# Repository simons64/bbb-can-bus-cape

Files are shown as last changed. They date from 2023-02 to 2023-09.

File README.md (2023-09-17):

# bbb-can-bus-cape
beaglebone black cape:
- 4x CANbus (up to 1Mbit, 2x direct CAN, 2x MCP2515)
- 1x RS485 up to 10 Mbit

## __design untested yet !__

Credits for the design to [@voloviq/bbb-can-bus-cape](https://github.com/voloviq/bbb-can-bus-cape)  
Design was adjusted for:
- currently available components from jlcpcb
- compatible interface for home ESS (Victron Multiplus 2 ; Victron MPPT RS 450 ; Pylontech US5000C)

## board 3D view

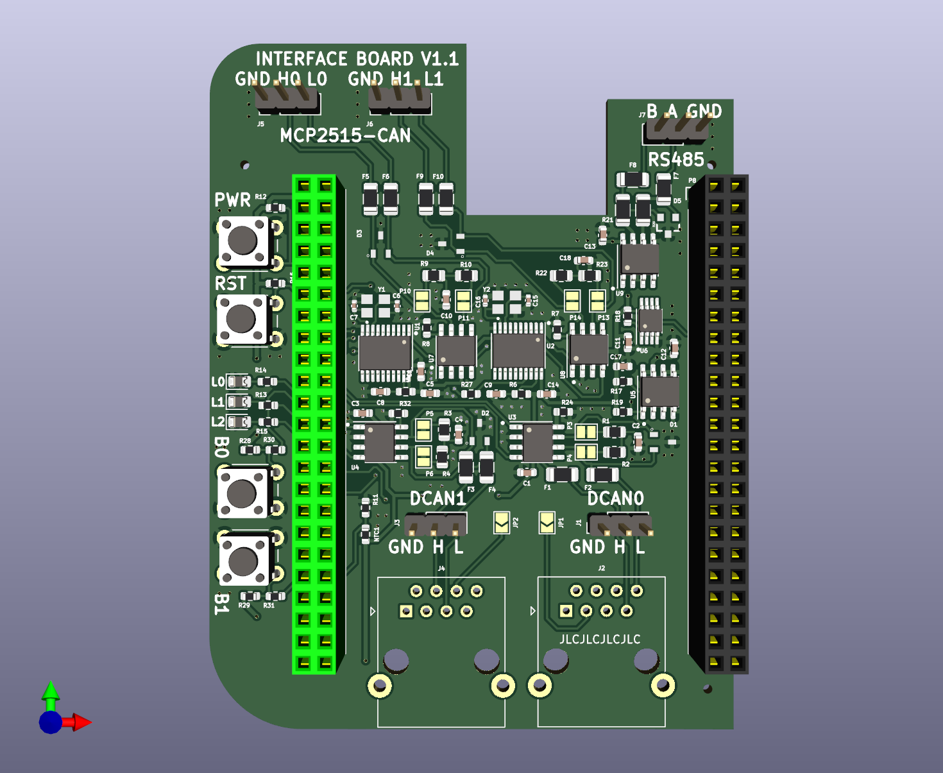
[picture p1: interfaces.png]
PCB_3D


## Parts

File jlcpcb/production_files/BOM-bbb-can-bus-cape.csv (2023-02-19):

Comment | Designator | Footprint | LCSC
SN65HVD230 | U3,U4,U7,U8 | SOIC-8_3.9x4.9mm_P1.27mm | C12084
X322516MLB4SI | Y1,Y2 | OSC_X322516MLB4SI | C13738
100nF/50V | C1,C10,C11,C12,C13,C14,C17,C18,C19,C2,C3,C4,C5,C8,C9 | C_0603_1608Metric | C14663
60R | R1,R10,R2,R22,R23,R3,R4,R9 | R_0805_2012Metric | C17757
10R | R20,R21 | R_1206_3216Metric | C17903
100R | R13,R14,R15,R27,R30,R31 | R_0603_1608Metric | C22775
LED | D6 | D_0805_2012Metric | C2296
LED | D7 | D_0805_2012Metric | C2297
4k7 | R11,R12,R16,R17,R18,R19,R28,R29 | R_0603_1608Metric | C23162
10k | R24,R32,R5,R6,R7,R8 | R_0603_1608Metric | C25804
PSM712 | D5 | SOT23-3 | C32677
10pF/50V | C15,C16,C6,C7 | C_0402_1005Metric | C32949
Polyfuse_Small | F1,F10,F2,F3,F4,F5,F6,F7,F8,F9 | Fuse_1206_3216Metric | C438898
PESD2CAN,215 | D1,D2,D3,D4 | SOT95P230X110-3N | C75176
LED | D8 | D_0805_2012Metric | C84256
SP3485EN | U9 | SOIC-8_3.9x4.9mm_P1.27mm | C8963

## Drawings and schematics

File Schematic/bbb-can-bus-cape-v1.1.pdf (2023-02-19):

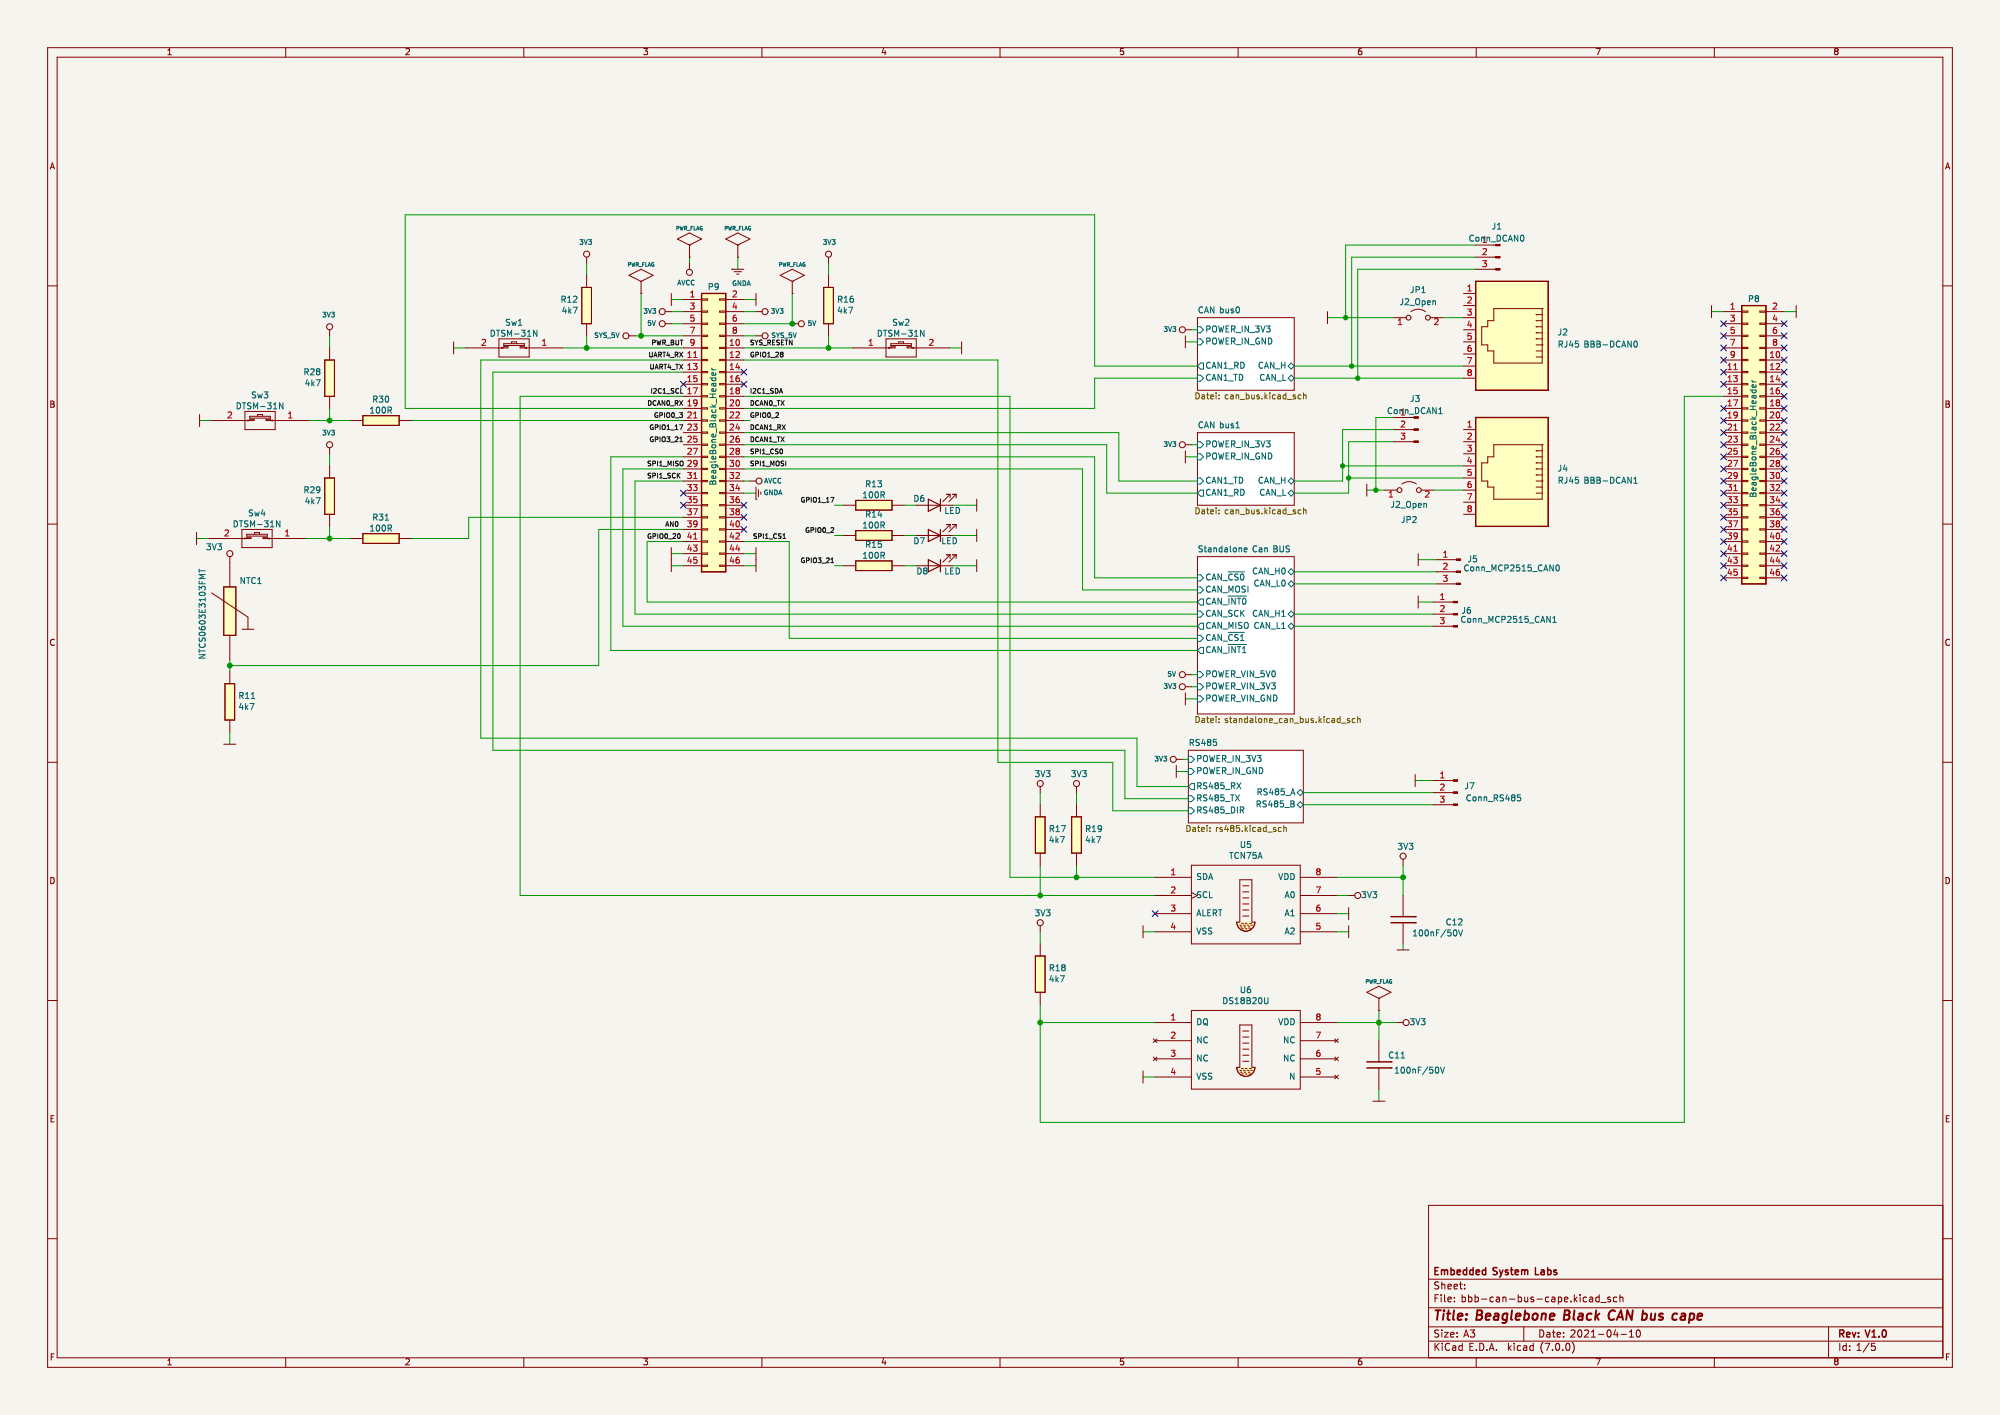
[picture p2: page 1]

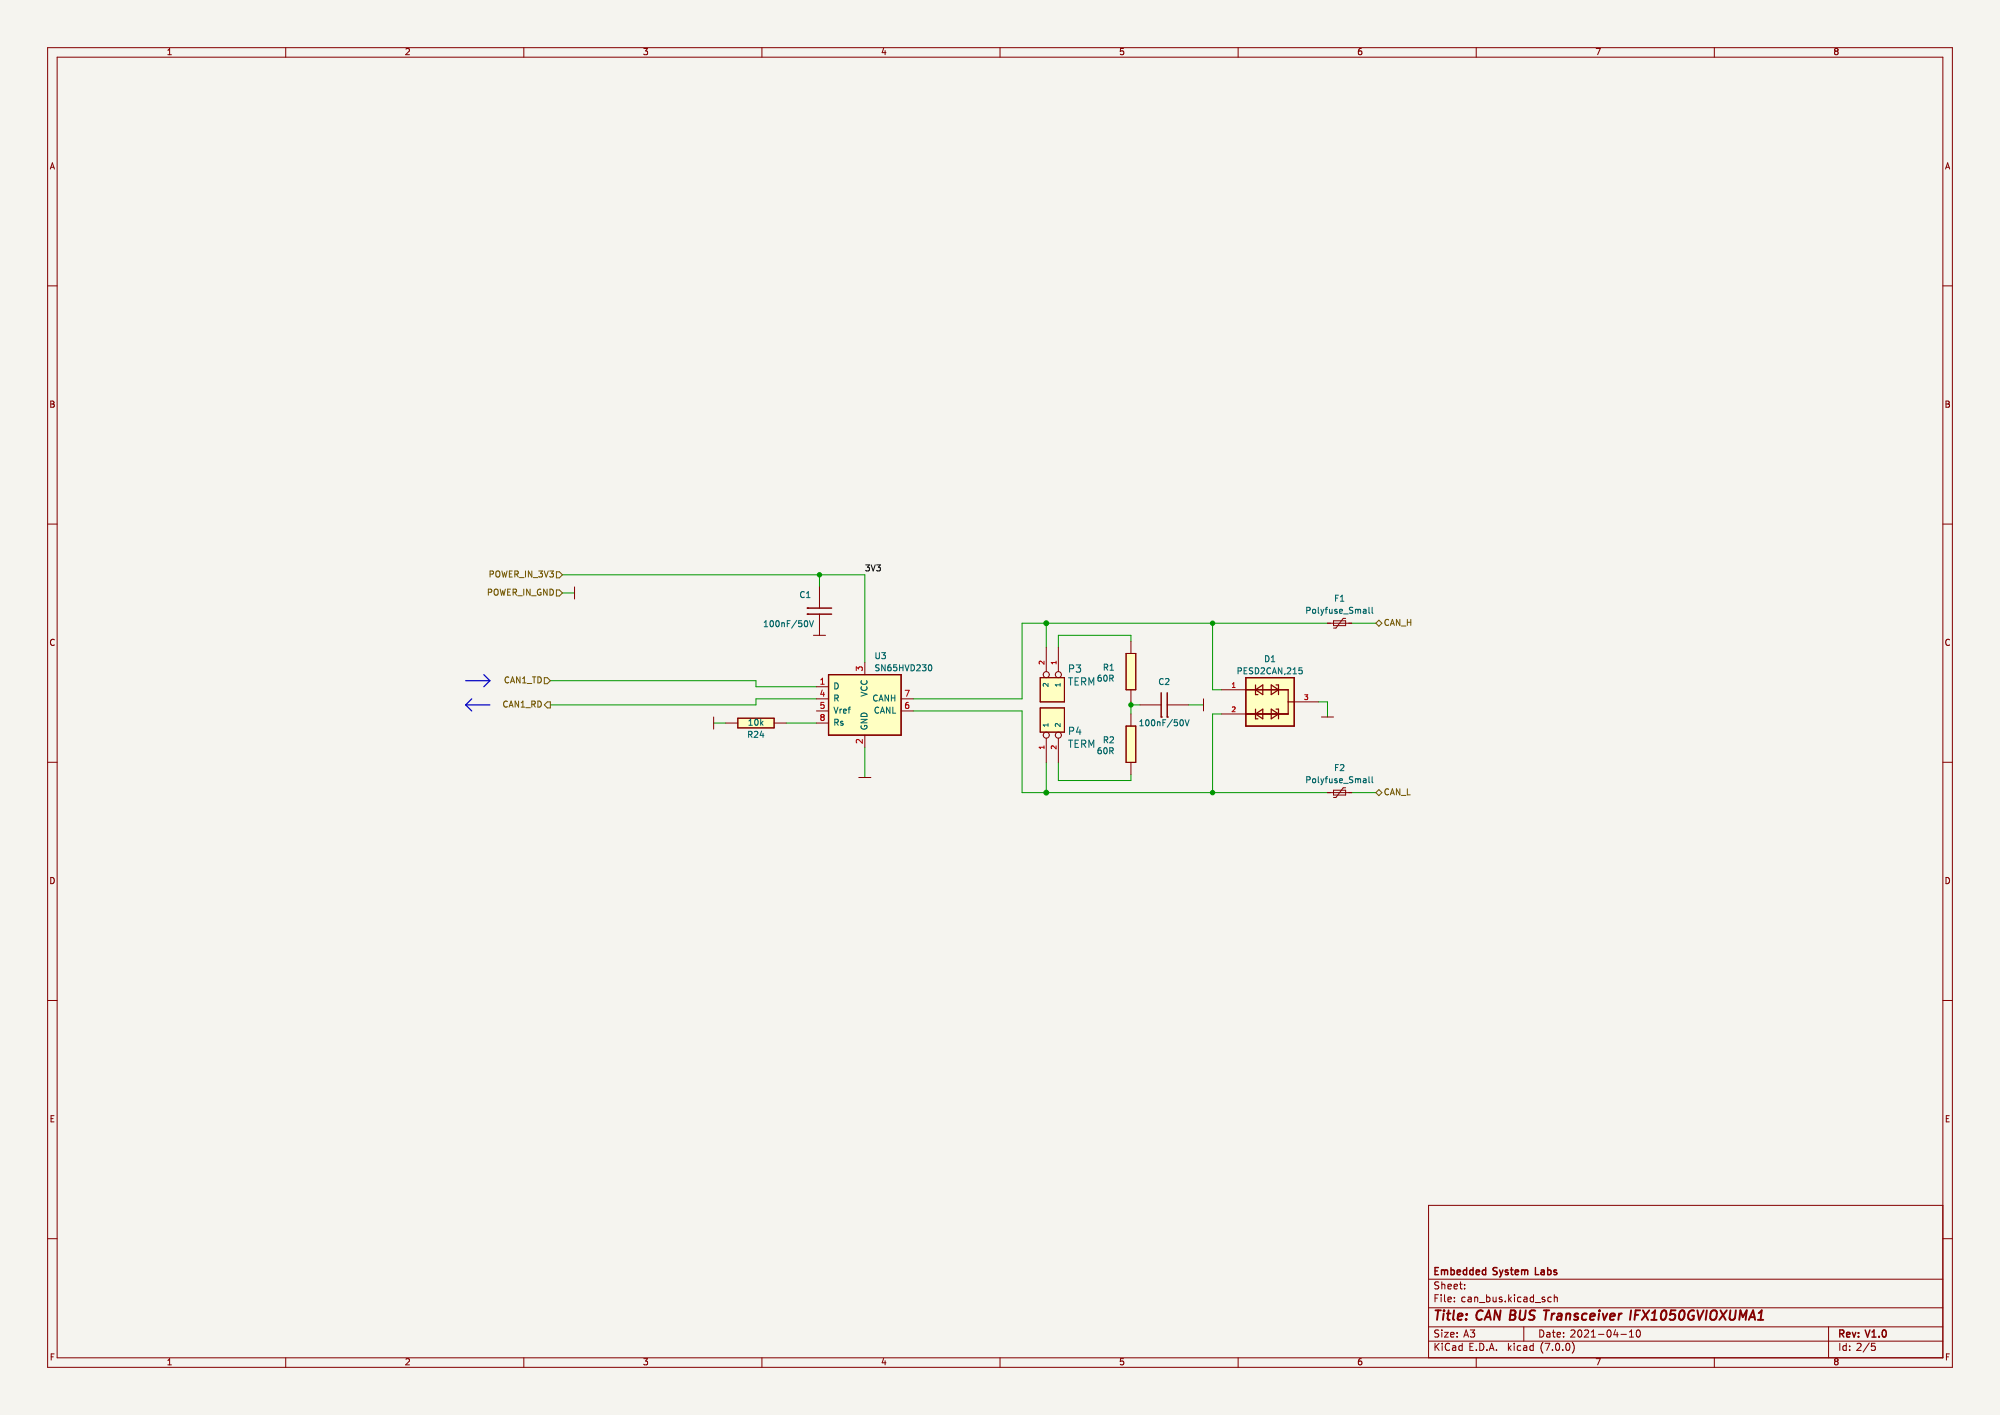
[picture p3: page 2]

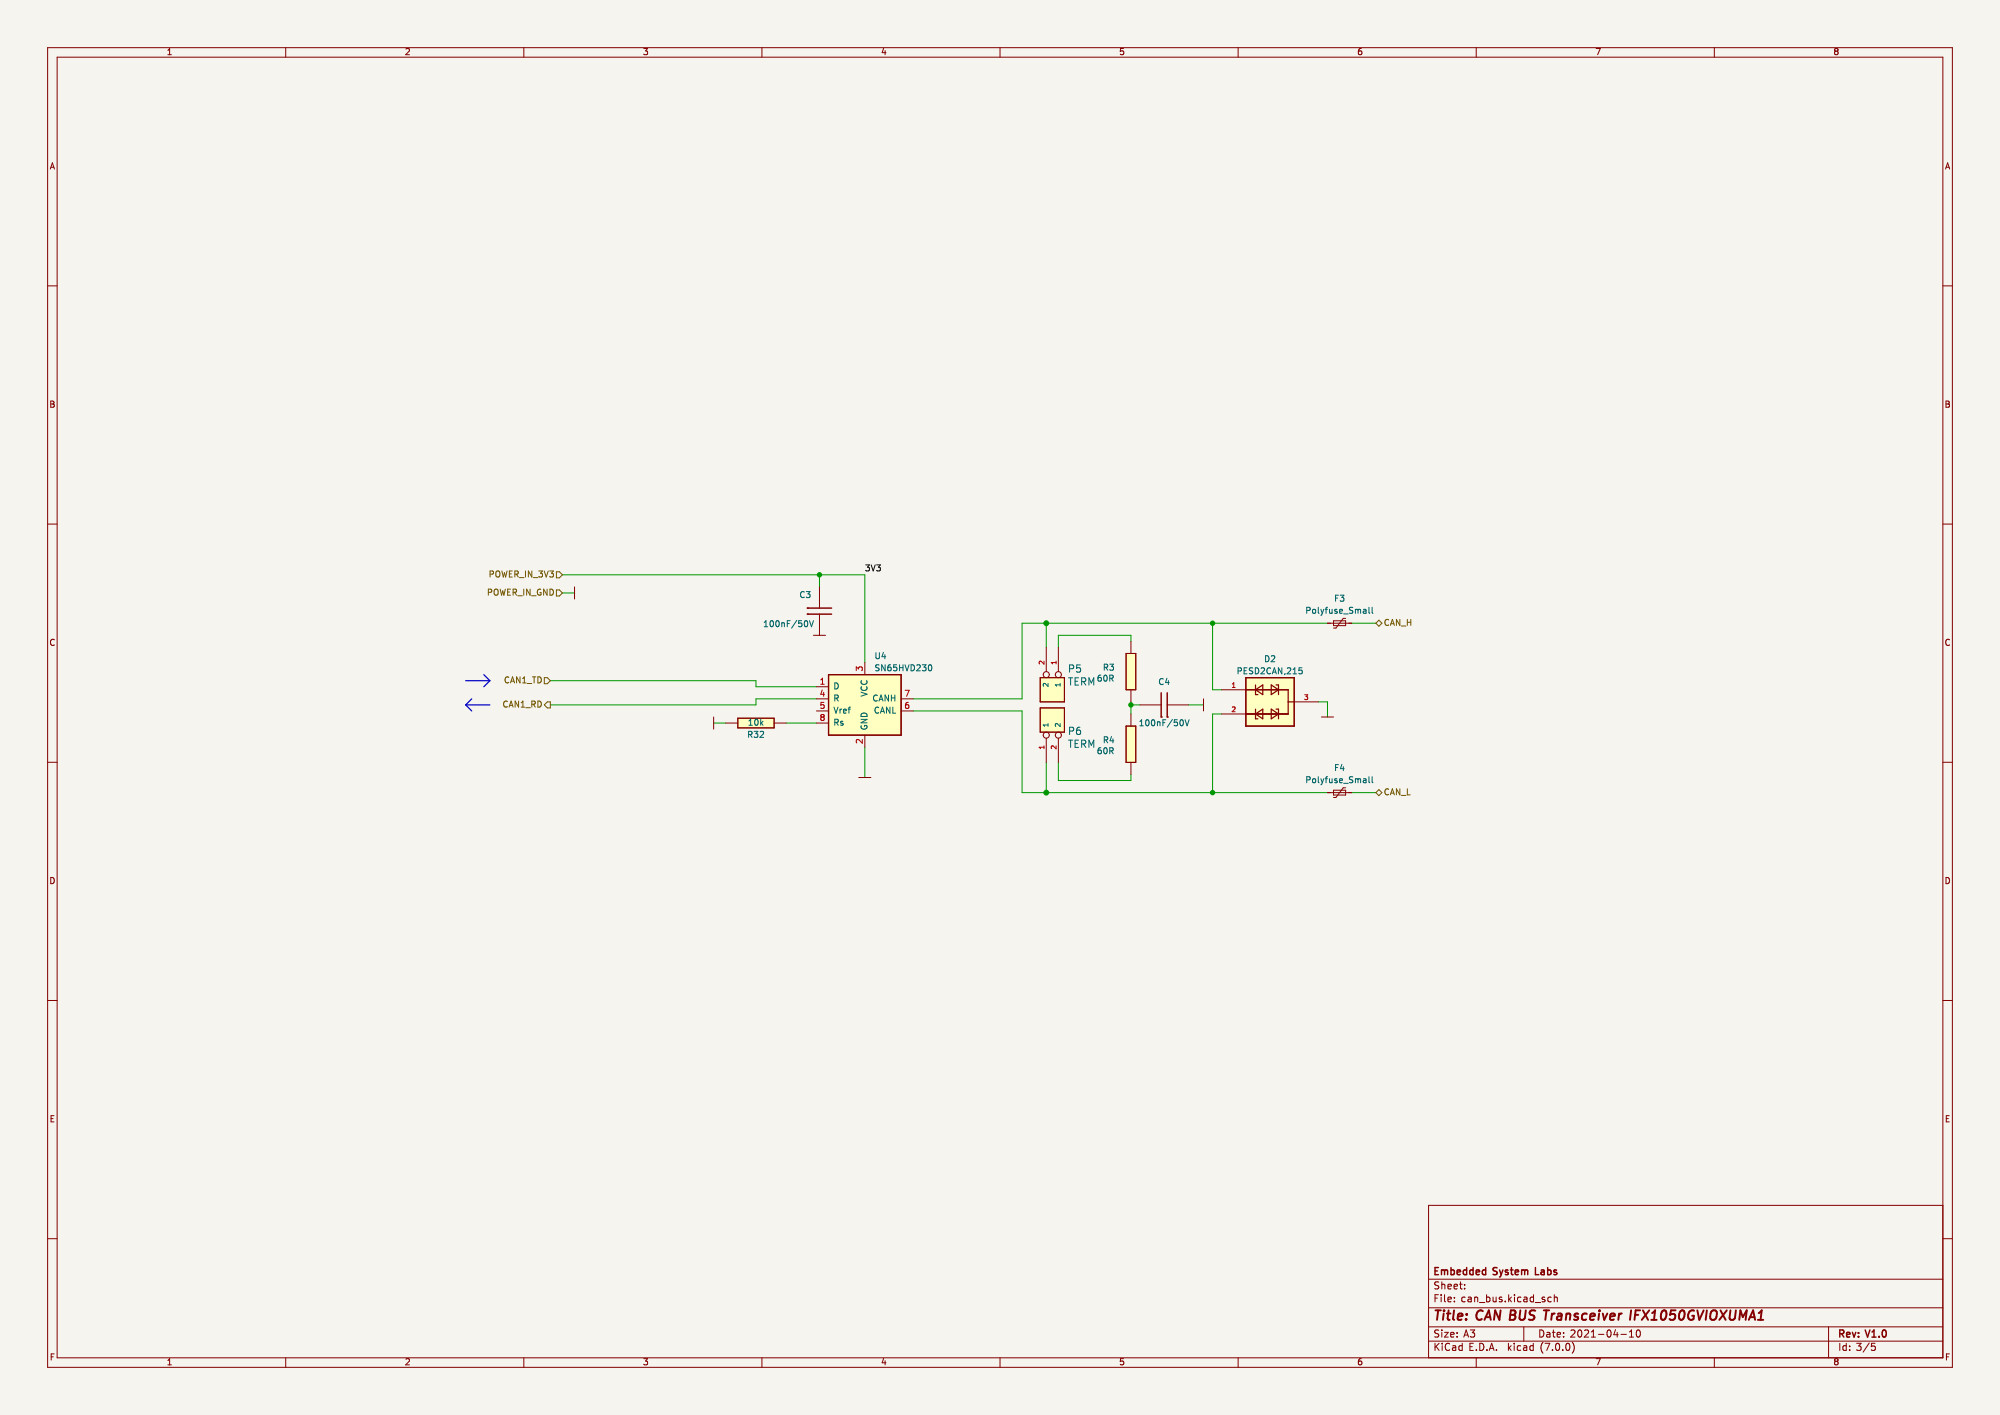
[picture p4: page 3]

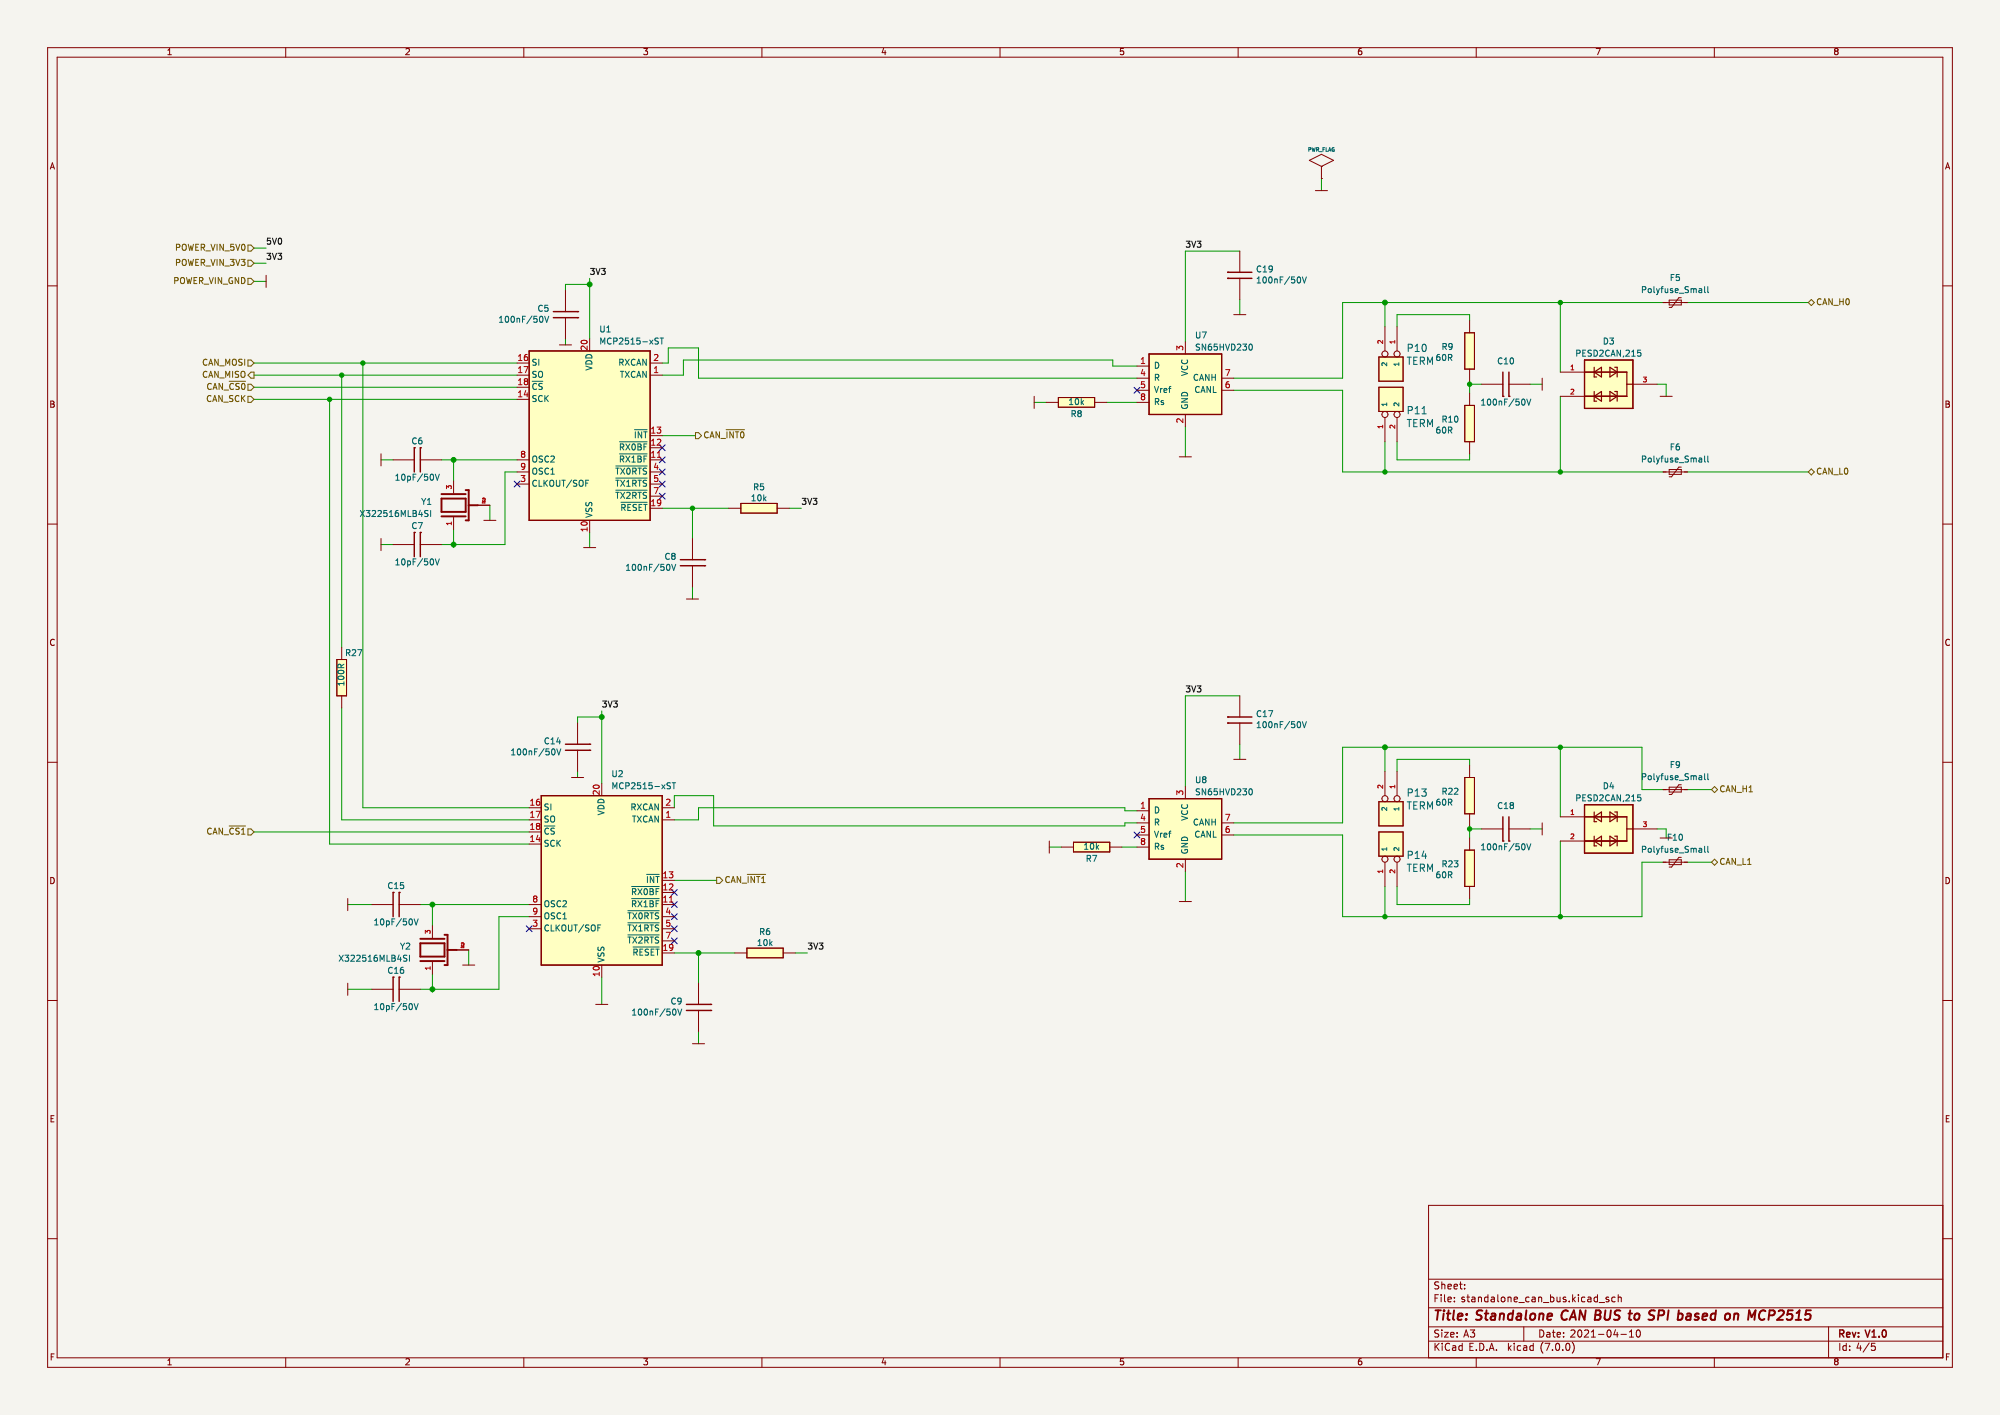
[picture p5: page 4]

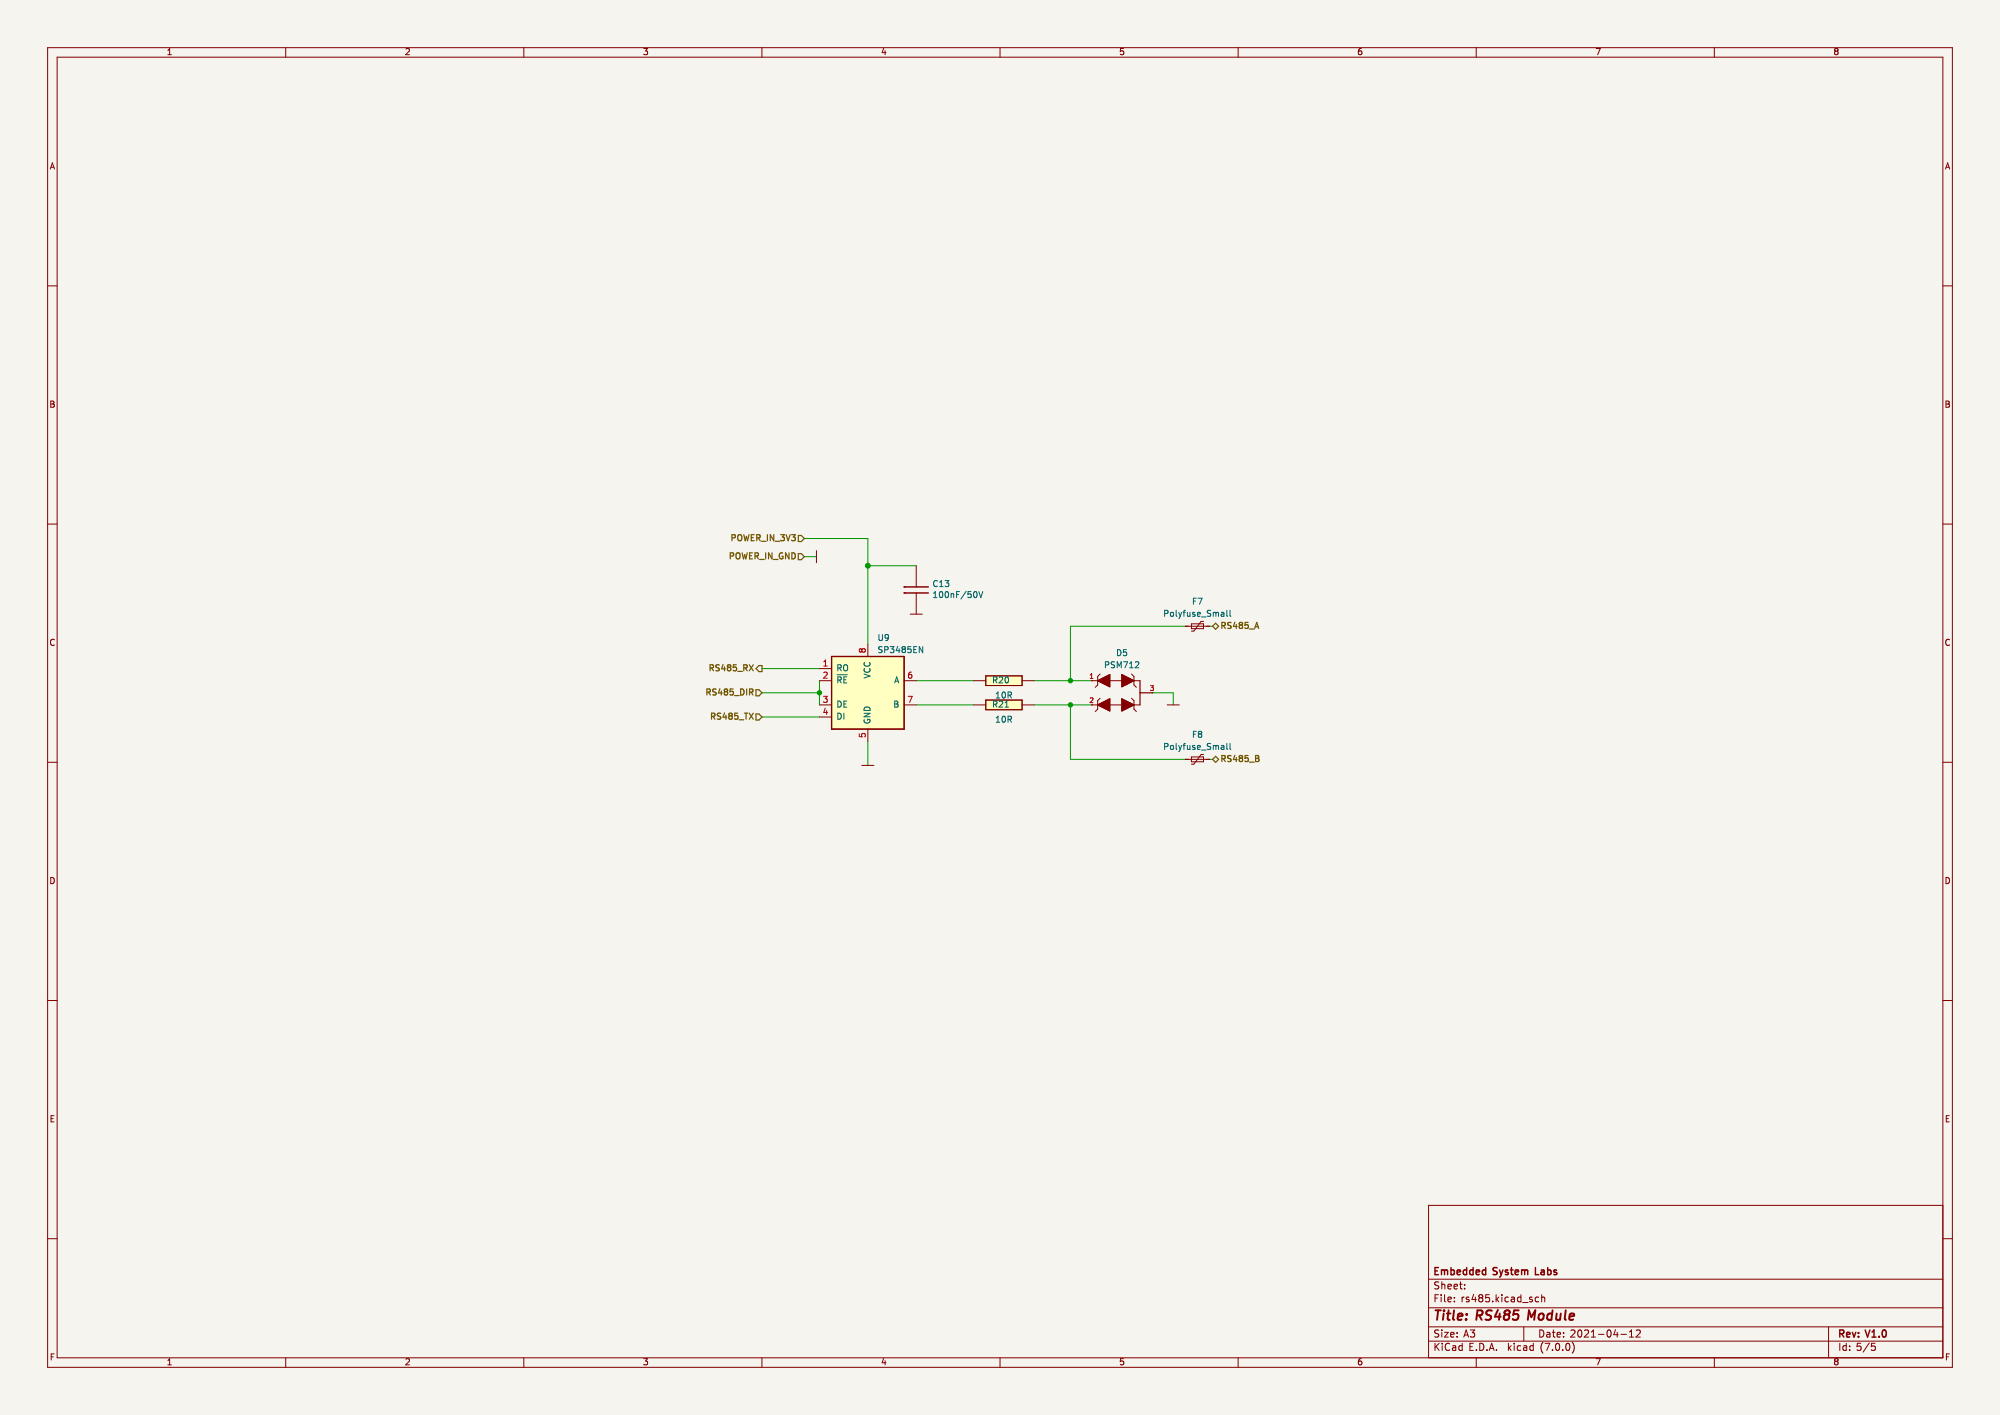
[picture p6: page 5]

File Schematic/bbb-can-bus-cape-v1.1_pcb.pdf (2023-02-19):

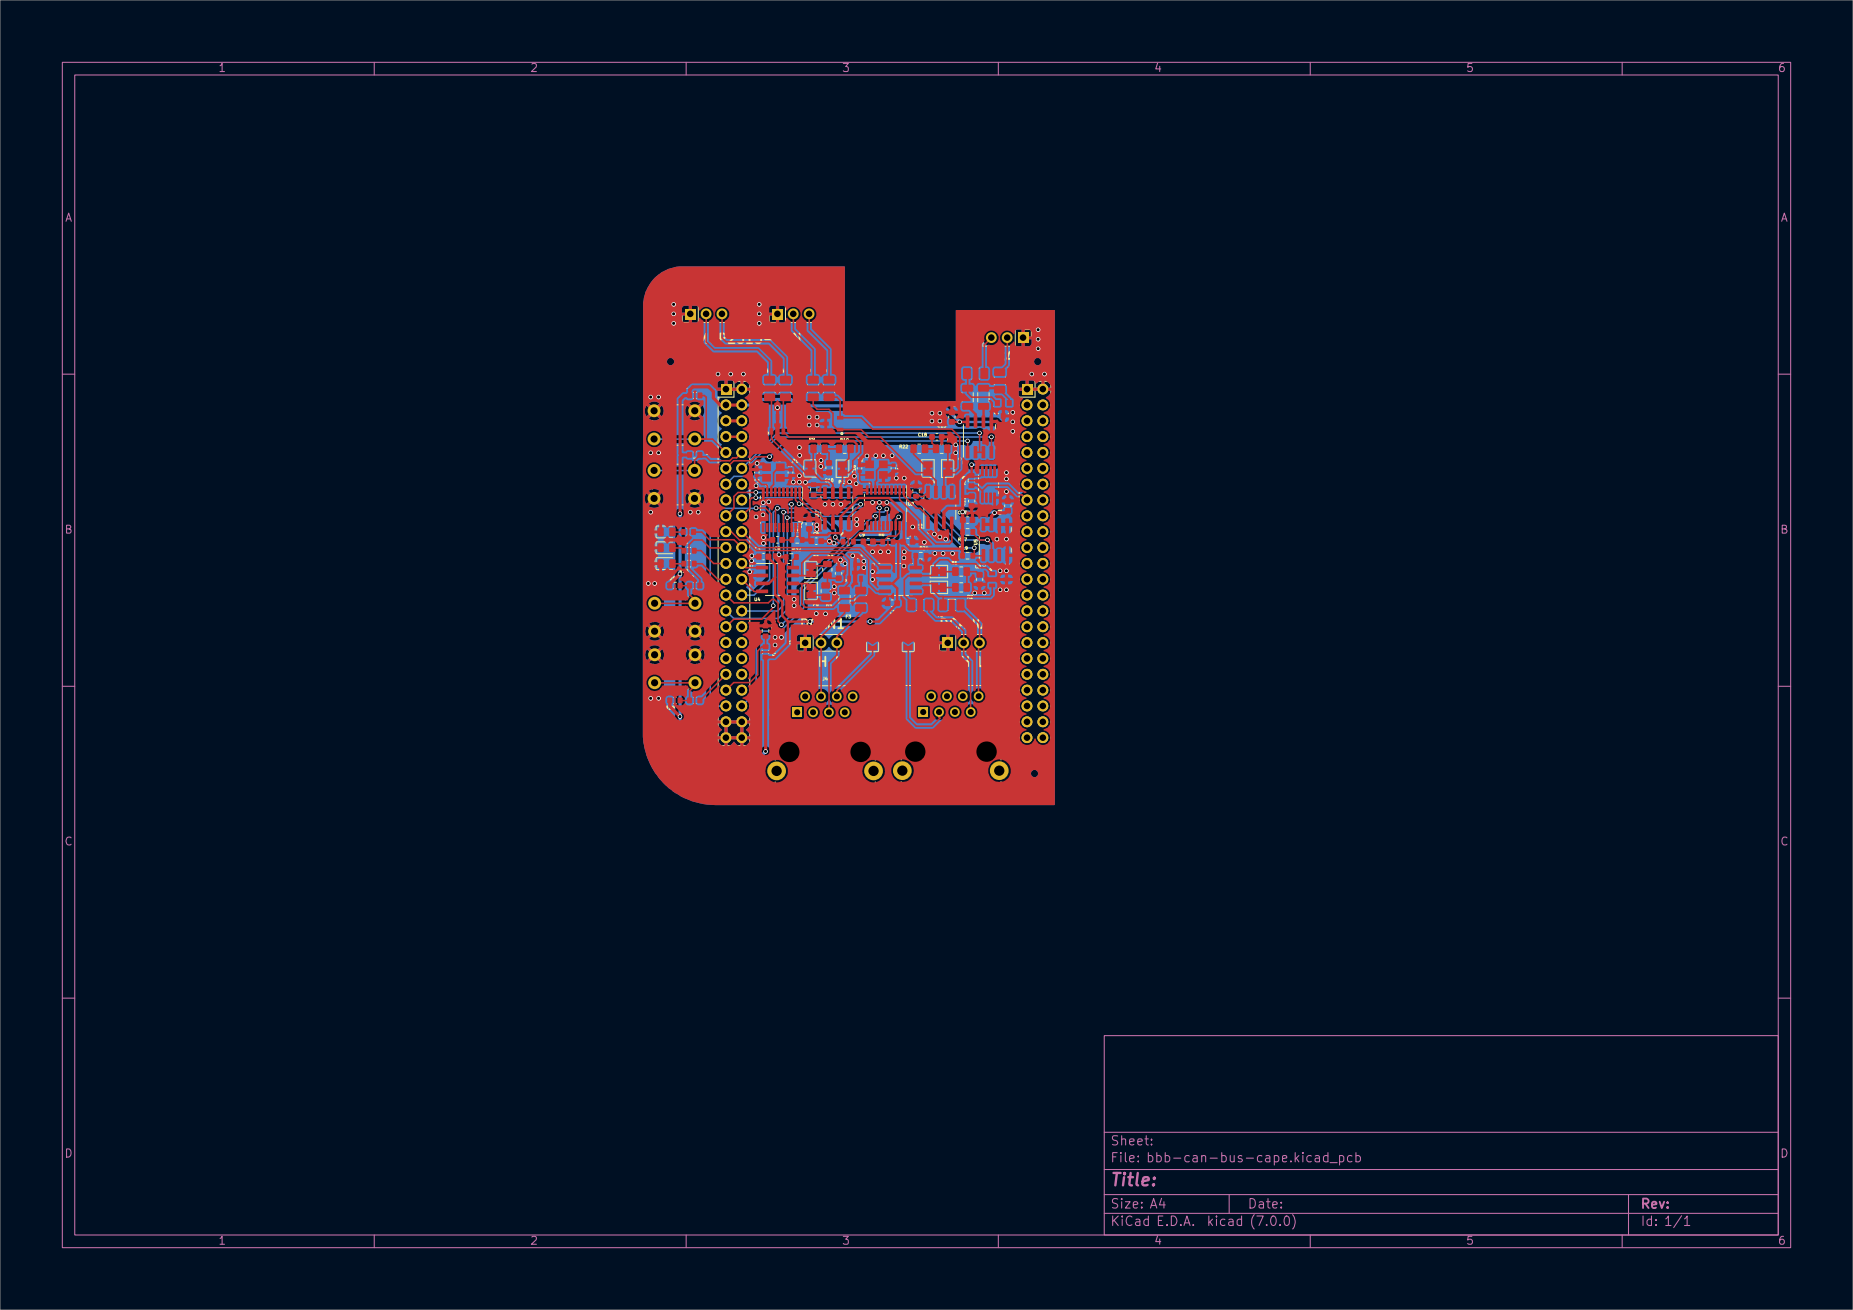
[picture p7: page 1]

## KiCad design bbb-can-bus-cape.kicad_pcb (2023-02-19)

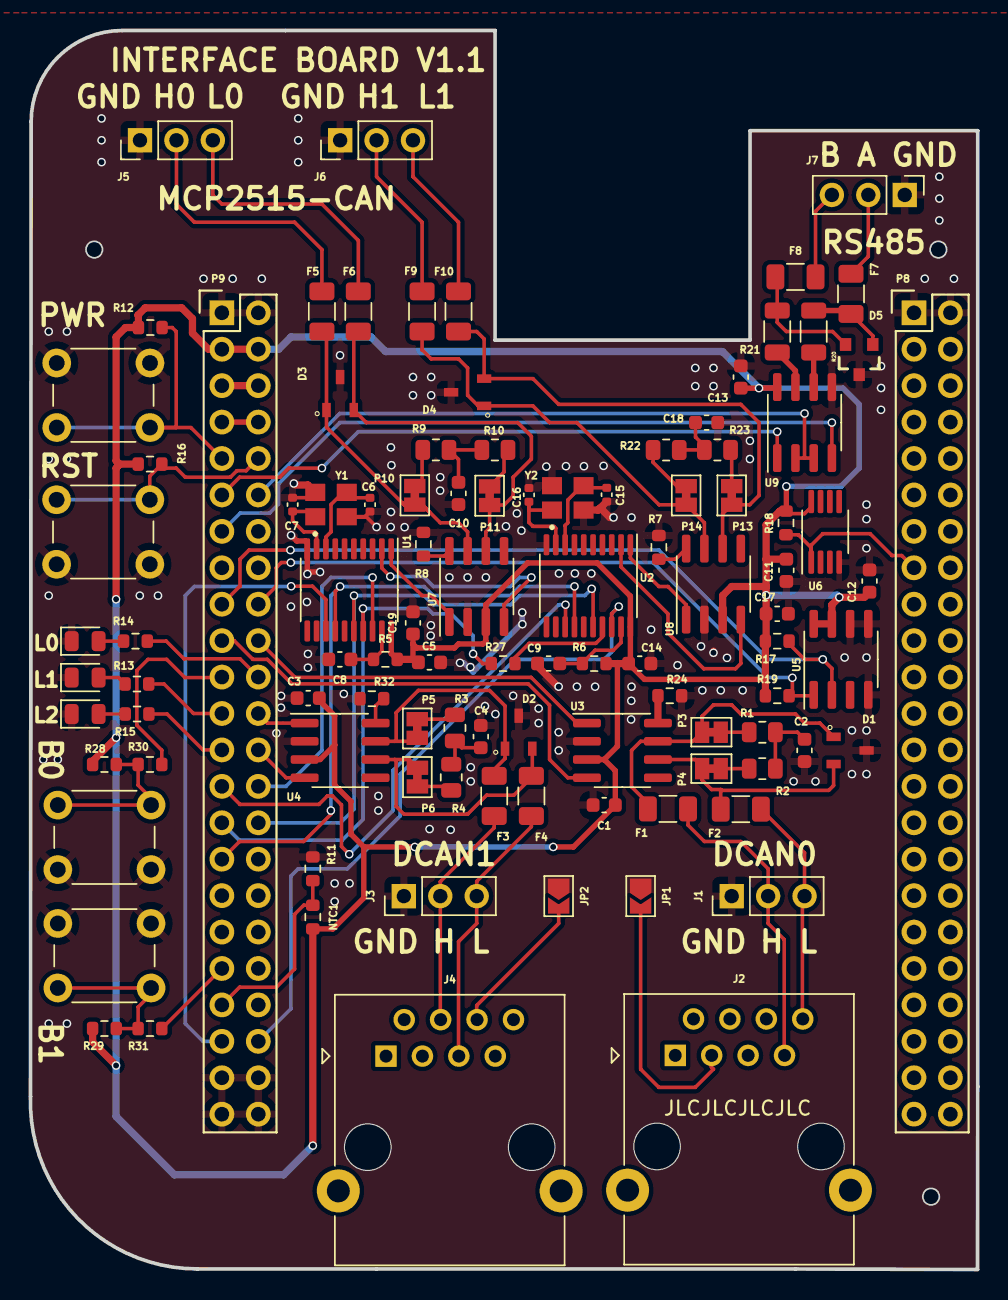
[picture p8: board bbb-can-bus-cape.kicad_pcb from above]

Board: 2 copper layers, 66.0 x 86.4 mm, 102 parts (0 on the bottom side), 85 nets.

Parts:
C1, C2, C3, C4, C5, C8, C9, C10, C11, C12, C13, C14, C17, C18, C19: 100nF/50V; C_0603_1608Metric
C6, C7, C15, C16: 10pF/50V; C_0402_1005Metric
D1, D2, D3, D4: PESD2CAN,215; SOT95P230X110-3N
D5: PSM712; SOT23-3
D6, D7, D8: LED; D_0805_2012Metric
F1, F2, F3, F4, F5, F6, F7, F8, F9, F10: Polyfuse_Small; Fuse_1206_3216Metric
J1: Conn_DCAN0; PinHeader_1x03_P2.54mm_Vertical
J2: RJ45 BBB-DCAN0; RJ45_Ninigi_GE
J3: Conn_DCAN1; PinHeader_1x03_P2.54mm_Vertical
J4: RJ45 BBB-DCAN1; RJ45_Ninigi_GE
J5: Conn_MCP2515_CAN0; PinHeader_1x03_P2.54mm_Vertical
J6: Conn_MCP2515_CAN1; PinHeader_1x03_P2.54mm_Vertical
J7: Conn_RS485; PinHeader_1x03_P2.54mm_Vertical
JP1, JP2: J2_Open; SolderJumper-2_P1.3mm_Open_TrianglePad1.0x1.5mm
NTC1: NTCS0603E3103FMT; R_0603_1608Metric
P3, P4, P5, P6, P10, P11, P13, P14: TERM; SolderJumper-2_P1.3mm_Bridged_Pad1.0x1.5mm
P8, P9: BeagleBone_Black_Header; Socket_BeagleBone_Black
R1, R2, R3, R4, R9, R10, R22, R23: 60R; R_0805_2012Metric
R5, R6, R7, R8, R24, R32: 10k; R_0603_1608Metric
R11, R12, R16, R17, R18, R19, R28, R29: 4k7; R_0603_1608Metric
R13, R14, R15, R27, R30, R31: 100R; R_0603_1608Metric
R20, R21: 10R; R_1206_3216Metric
Sw1, Sw2, Sw3, Sw4: DTSM-31N; SW_PUSH_6mm
U1, U2: MCP2515-xST; TSSOP-20_4.4x6.5mm_P0.65mm
U3, U4, U7, U8: SN65HVD230; SOIC-8_3.9x4.9mm_P1.27mm
U5: TCN75A; SOIC-8_3.9x4.9mm_P1.27mm
U6: DS18B20U; MSOP-8_3x3mm_P0.65mm
U9: SP3485EN; SOIC-8_3.9x4.9mm_P1.27mm
Y1, Y2: X322516MLB4SI; OSC_X322516MLB4SI

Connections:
3V3: C1.1, C3.1, C5.1, C11.1, C12.1, C13.1, C14.1, C17.1, C19.1, NTC1.2, P9.3, P9.4, R5.2, R6.2, R12.1, R16.1, R17.1, R18.1, R19.1, R28.1, R29.1, U1.20 (VDD), U2.20 (VDD), U3.3 (VCC), U4.3 (VCC), U5.7 (A0), U5.8 (VDD), U6.8 (VDD), U7.3 (VCC), U8.3 (VCC), U9.8 (VCC)
5V: P9.5, P9.6
/AN0: NTC1.1, P9.39, R11.1
/CAN bus0/CAN_H: F1.2, J1.2, J2.7
/CAN bus0/CAN_L: F2.2, J1.3, J2.8
/CAN bus1/CAN_H: F3.2, J3.2, J4.4
/CAN bus1/CAN_L: F4.2, J3.3, J4.5
/DCAN0_RX: P9.19, U3.4 (R)
/DCAN0_TX: P9.20, U3.1 (D)
/DCAN1_RX: P9.24, U4.1 (D)
/DCAN1_TX: P9.26, U4.4 (R)
/GPIO0_2: P9.22, R14.1
/GPIO0_3: P9.21, R30.2
/GPIO0_20: P9.41, U1.13 (~INT)
/GPIO1_17: P9.23, R13.1
/GPIO1_28: P9.12, U9.2 (~RE), U9.3 (DE)
/GPIO3_21: P9.25, R15.1
/I2C1_SCL: P9.17, R17.2, U5.2 (SCL)
/I2C1_SDA: P9.18, R19.2, U5.1 (SDA)
/PWR_BUT: P9.9, R12.2, Sw1.1
/RS485/RS485_A: F7.2, J7.2
/RS485/RS485_B: F8.2, J7.3
/SPI1_CS0: P9.28, U1.18 (~CS)
/SPI1_CS1: P9.42, U2.18 (~CS)
/SPI1_MISO: P9.29, R27.1, U1.17 (SO)
/SPI1_MOSI: P9.30, U1.16 (SI), U2.16 (SI)
/SPI1_SCK: P9.31, U1.14 (SCK), U2.14 (SCK)
/SYS_RESETN: P9.10, R16.2, Sw2.1
/Standalone Can BUS/CAN_H0: F5.2, J5.2
/Standalone Can BUS/CAN_H1: F9.2, J6.2
/Standalone Can BUS/CAN_L0: F6.2, J5.3
/Standalone Can BUS/CAN_L1: F10.2, J6.3
/Standalone Can BUS/CAN_~INT1: P9.27, U2.13 (~INT)
/UART4_RX: P9.11, U9.1 (RO)
/UART4_TX: P9.13, U9.4 (DI)
GND: C1.2, C2.2, C3.2, C4.2, C5.2, C6.2, C7.2, C8.2, C9.2, C10.2, C11.2, C12.2, C13.2, C14.2, C15.2, C16.2, C17.2, C18.2, C19.2, D1.3, D2.3, D3.3, D4.3, D5.3, D6.1 (K), D7.1 (K), D8.1 (K), J1.1, J3.1, J5.1, J6.1, J7.1, JP1.1 (A), JP2.1 (A), P8.1, P8.2, P9.1, P9.2, P9.43, P9.44, P9.45, P9.46, R7.2, R8.2, R11.2, R24.2, R32.2, Sw1.2, Sw2.2, Sw3.2, Sw4.2, U1.10 (VSS), U2.10 (VSS), U3.2 (GND), U4.2 (GND), U5.4 (VSS), U5.5 (A2), U5.6 (A1), U6.4 (VSS), U7.2 (GND), U8.2 (GND), U9.5 (GND), Y1.2, Y1.4, Y2.2, Y2.4
unnamed: C2.1, R1.2, R2.1
unnamed: C4.1, R3.2, R4.1
unnamed: C10.1, R9.2, R10.1
unnamed: C18.1, R22.2, R23.1
unnamed: D5.1, F7.1, R20.2
unnamed: D5.2, F8.1, R21.2
unnamed: D6.2 (A), R13.2
unnamed: D7.2 (A), R14.2
unnamed: D8.2 (A), R15.2
unnamed: J2.3, JP1.2 (B)
unnamed: J4.6, JP2.2 (B)
unnamed: P3.1, R1.1
unnamed: P4.2, R2.2
unnamed: P5.1, R3.1
unnamed: P6.2, R4.2
unnamed: P8.15, R18.2, U6.1 (DQ)
unnamed: P9.37, R31.2
unnamed: P10.1, R9.1
unnamed: P11.2, R10.2
unnamed: P13.1, R22.1
unnamed: P14.2, R23.2
unnamed: R28.2, R30.1, Sw3.1
unnamed: R29.2, R31.1, Sw4.1
unnamed: C7.1, U1.9 (OSC1), Y1.1
unnamed: C6.1, U1.8 (OSC2), Y1.3
unnamed: U1.2 (RXCAN), U7.4 (R)
unnamed: U1.1 (TXCAN), U7.1 (D)
unnamed: C8.1, R5.1, U1.19 (~RESET)
unnamed: C16.1, U2.9 (OSC1), Y2.1
unnamed: C15.1, U2.8 (OSC2), Y2.3
unnamed: U2.2 (RXCAN), U8.4 (R)
unnamed: R27.2, U2.17 (SO)
unnamed: U2.1 (TXCAN), U8.1 (D)
unnamed: C9.1, R6.1, U2.19 (~RESET)
unnamed: D1.1, F1.1, P3.2, U3.7 (CANH)
unnamed: D1.2, F2.1, P4.1, U3.6 (CANL)
unnamed: R24.1, U3.8 (Rs)
unnamed: D2.1, F3.1, P5.2, U4.7 (CANH)
unnamed: D2.2, F4.1, P6.1, U4.6 (CANL)
unnamed: R32.1, U4.8 (Rs)
unnamed: D3.1, F5.1, P10.2, U7.7 (CANH)
unnamed: D3.2, F6.1, P11.1, U7.6 (CANL)
unnamed: R8.1, U7.8 (Rs)
unnamed: D4.1, F9.1, P13.2, U8.7 (CANH)
unnamed: D4.2, F10.1, P14.1, U8.6 (CANL)
unnamed: R7.1, U8.8 (Rs)
unnamed: R20.1, U9.6 (A)
unnamed: R21.1, U9.7 (B)
SYS_5V: P9.7, P9.8

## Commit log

2023-02-19 created new layout for adjusted schematic
    [BOM-bbb-can-bus-cape.csv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]
2023-02-19 add new screenshots and change pcb picture
